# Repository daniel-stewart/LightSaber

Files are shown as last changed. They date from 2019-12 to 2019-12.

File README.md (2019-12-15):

# LightSaber
This repo contains files related to creating 3D lightsabers in Blender that can then be printed out and electroincs inserted. 
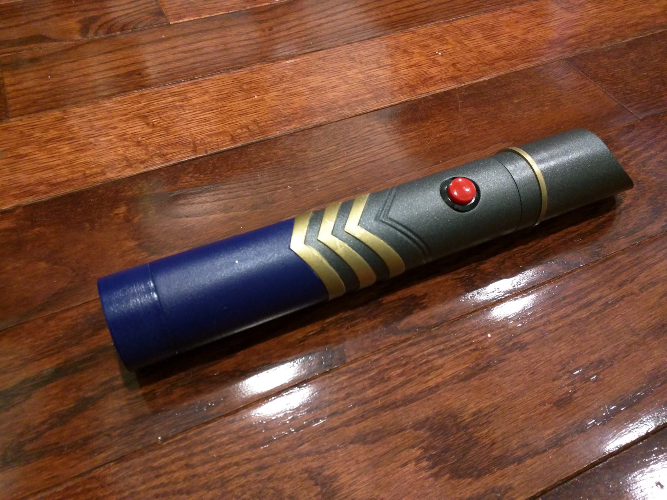
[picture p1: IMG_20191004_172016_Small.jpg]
Lightsaer


## Light Saber Maker Python File
This file will create the basic parts for a lightsaber.
1) Open Blender 2.8 or above.
2) Go to the __Scripting__ tab
3) Choose the open button in the editor and load the LightSaberMaker.py file.
4) Hit __Run Scripts__ button.

The basic parts should be created for you. They are very large compared to Blender units because, by default, Blender exports with 1m = 1mm when exporting STL files. Yes, I could change the default, but I tried to make it easy on my students by allowing them to simply export with default settings.

At the bottom of the Python file you'll see the calls to the various functions which create the hilt, pommel, and blade holder. You can alter the parameters that are used to create the parts. You should be able to look at the function definitions to see what each parameter does. The basic parameters control the number of vertices around, the number of threads, the radius of the lightsaber, and the thread profile.

This just creates parts from which you can continue to make into what you want. They should screw together just fine once printed, assuming you've made the number of threads for male and female such that they fit. 

The Blade Holder was sized to fit standard blades you can get within this hobby space. For example, I bought a blade tube from [The Custom Saber Shop](https://www.thecustomsabershop.com/1-Thick-walled-Trans-White-PolyC-40-long-P528.aspx) and it fits just fine. 

## M4 Lightsaber Code
The M4 Lightsaber Python file is the code that can be loaded onto an [Adafruit M4 Express Feather](https://www.adafruit.com/product/3857) + [PropWing](https://www.adafruit.com/product/3988) to turn the lightsaber on and off. It is very basic code that turns the lightsaber on with one press of the external button and turns it back off when the button is pressed again. The sounds are standard 22kHz, 16-bit WAV files. A very basic usage of the "tap" detection is used to play a sound when lightsabers are hit and momentarily turn the blade all white. I have not included the WAV files, as they are not mine to include. Search the web for whatever sound files you like. 

I used a [standard battery common for lightsabers](https://www.thecustomsabershop.com/JST-Sony-Li-Ion-18650-37V-15A-3120mAh-PCB-Protected-Rechargeable-Battery-P1451.aspx).

I bought regular 22mm speakers off the Internet to use for my sound. 

## Chassis
I've included STL files of the chassis I used to hold the electronics. Not the best design in the world, but it worked.
I designed the hilt such that the chassis slides down and is stopped near the bottom. The inside radius of the tube is simply smaller at th bottom, stopping the chassis from falling all the way through. I held my chassis in place with the button. The button is positioned such that it prevents the chassis from sliding up. Simple, but it works. The distance from the center of the button to the top of the set of points inside the hilt where it begins getting smaller is 142.69 m.

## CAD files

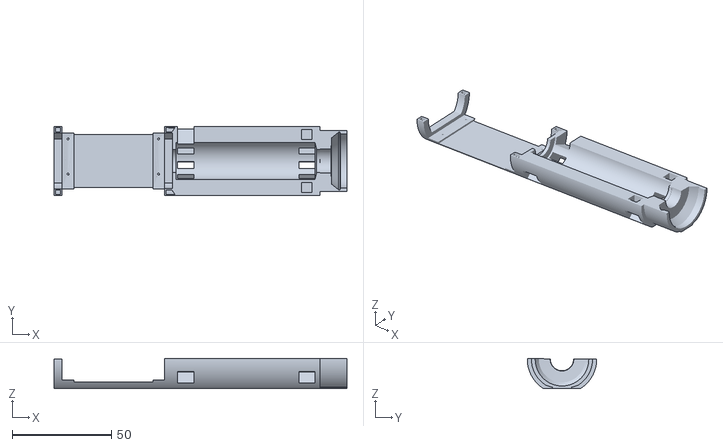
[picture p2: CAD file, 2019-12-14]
BatteryChassis6PrintReady2-Cylinder_004.stl
147.7 x 35.0 x 15.3

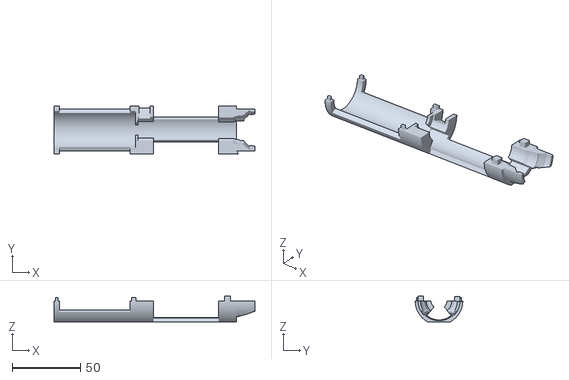
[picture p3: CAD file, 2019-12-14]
BatteryChassis6PrintReady2-Cylinder_003.stl
147.7 x 35.0 x 19.0

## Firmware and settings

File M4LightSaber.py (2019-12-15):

'''
Copyright 2019, Daniel Stewart

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
You should have received a copy of the GNU General Public License
along with this program.  If not, see <https://www.gnu.org/licenses/>.
'''
import board
import time
import neopixel
import digitalio
import busio
import adafruit_lis3dh
import random

try:
    from audiocore import WaveFile
except ImportError:
    from audioio import WaveFile

try:
    from audioio import AudioOut
except ImportError:
    try:
        from audiopwmio import PWMAudioOut as AudioOut
    except ImportError:
        pass  # not always supported by every board!

# define constants
COLOR=(0,0,255)
NUM_PIXELS = 131
NEOPIXEL_PIN = board.D5
POWER_PIN = board.D10
SWITCH_PIN = board.D9

# set up audio
audiofiles = ["sounds/LSOn.wav", "sounds/LSOff.wav", "sounds/LightSaberClash1.wav", "sounds/LightSaberClash2.wav",
              "sounds/LightSaberClash3.wav", "sounds/LightSaberClash4.wav"]
audio = AudioOut(board.A0)

# Set up NeoPixels
neopixels = neopixel.NeoPixel(NEOPIXEL_PIN, NUM_PIXELS, brightness=1)
neopixels.fill((0,0,0))
#neopixels.show()

# Set up on/off button
button = digitalio.DigitalInOut(SWITCH_PIN)
button.switch_to_input(pull=digitalio.Pull.UP)
prevPress = False
on = False
clashNum = 2

# Set up accelerometer on I2C bus, 4G range:
i2c = busio.I2C(board.SCL, board.SDA)
int1 = digitalio.DigitalInOut(board.D6)
lis3dh = adafruit_lis3dh.LIS3DH_I2C(i2c, int1=int1)
lis3dh.range = adafruit_lis3dh.RANGE_8_G
lis3dh.set_tap(1, 90, time_limit=4, time_latency=50, time_window=255)

enable = digitalio.DigitalInOut(POWER_PIN)
enable.direction = digitalio.Direction.OUTPUT
enable.value = False

redled = digitalio.DigitalInOut(board.D13)
redled.direction = digitalio.Direction.OUTPUT
led = neopixel.NeoPixel(board.NEOPIXEL, 1);
led.brightness = 0.2

redled.value = False
def play_file(filename):
    print("Playing file: " + filename)
    wave_file = open(filename, "rb")
    with WaveFile(wave_file) as wave:
        audio.play(wave)
        while audio.playing:
            pass
        wave_file.close()
    print("Finished")

def lightSaberOn():
    i = 0
    enable.value = True
    wave_file = open(audiofiles[0], "rb")
    redled.value = True
    with WaveFile(wave_file) as wave:
        audio.play(wave)
        while audio.playing:
            neopixels[i] = (0,0,255)
            i = (i + 1) % NUM_PIXELS
        wave_file.close()
    print("Finished")

def lightSaberOff():
    wave_file = open(audiofiles[1], "rb")
    redled.value = False
    i = NUM_PIXELS - 1
    with WaveFile(wave_file) as wave:
        audio.play(wave)
        while audio.playing:
            neopixels[i] = (0,0,0)
            i = (i - 1)
            if i < 0:
                i = 0
        wave_file.close()
    enable.value = False
    print("Finished")

def flashOnClash():
    global clashNum
    wave_file = open(audiofiles[clashNum], "rb")
    with WaveFile(wave_file) as wave:
        audio.play(wave)
        neopixels.fill((255,255,255))
        led.fill((255,255,255))
        while audio.playing:
            neopixels.fill((0,0,255))
            led.fill((0,0,255))
        wave_file.close()
    clashNum = random.randint(2,5)

while True:
    x,y,z = lis3dh.acceleration
    if lis3dh.tapped and on:
        flashOnClash()
    if x > 8 and y < 1 and z < 1:
        led[0] = (255,255,0)
    elif x < 1 and y > 8 and z < 1:
        led[0] = (0,255,255)
    elif x < 1 and y < 1 and z > 8:
        led[0] = (255,0,255)
    else:
        led[0] = (0,0,0)
    if not button.value and not prevPress:
        if not on:
            lightSaberOn()
        else:
            lightSaberOff()
        prevPressfor = True
        on = not on
    elif button.value and prevPress:
        prevPress = False

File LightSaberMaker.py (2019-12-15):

'''
Copyright 2019, Daniel Stewart

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
You should have received a copy of the GNU General Public License
along with this program.  If not, see <https://www.gnu.org/licenses/>.
'''
import bpy
import bmesh
from math import *

def createMeshFromData(name, origin, verts, edges, faces):
    # Create mesh and object
    mesh = bpy.data.meshes.new(name+'Mesh')
    ob = bpy.data.objects.new(name, mesh)
    ob.location = origin
    ob.show_name = False
    # Link object to scene and make active
    bpy.context.collection.objects.link(ob)
    ob.select_set(True)
    # Create mesh from given verts, faces.
    mesh.from_pydata(verts, edges, faces)
    bm = bmesh.new()
    bm.from_mesh(mesh)
    bmesh.ops.remove_doubles(bm, verts=bm.verts, dist=0.0001)
    bmesh.ops.recalc_face_normals(bm, faces=bm.faces)
    bm.to_mesh(mesh)
    mesh.update()
    bm.clear()

    bm.free()
    # Update mesh with new data
    mesh.update()

def createCircularPolys(VerticesPerLoop, verts, faces, radius, zoffset, startVert, startFace, joinVert, joinFace):
    angle = 0
    for i in range(VerticesPerLoop):
        angle = i * 2 * pi / VerticesPerLoop
        x = radius * cos(angle)
        y = radius * sin(angle)
        z = zoffset
       
        verts[startVert + i][0] = x
        verts[startVert + i][1] = y
        verts[startVert + i][2] = z
   
    for i in range(VerticesPerLoop - 1):
        faces[startFace + i][0] = startVert + i
        faces[startFace + i][1] = startVert + i + 1
        faces[startFace + i][2] = joinVert + 1 + i
        faces[startFace + i][3] = joinVert + i
   
    faces[startFace + VerticesPerLoop - 1][0] = startVert + VerticesPerLoop - 1
    faces[startFace + VerticesPerLoop - 1][1] = startVert
    faces[startFace + VerticesPerLoop - 1][2] = joinVert
    faces[startFace + VerticesPerLoop - 1][3] = joinVert + VerticesPerLoop - 1
   
def joinCircularPolys(VerticesPerLoop, verts, faces, startVert, startFace, joinVert):
    for i in range(VerticesPerLoop - 1):
        faces[startFace + i][0] = startVert + i
        faces[startFace + i][1] = startVert + i + 1
        faces[startFace + i][2] = joinVert + 1 + i
        faces[startFace + i][3] = joinVert + i
   
    faces[startFace + VerticesPerLoop - 1][0] = startVert + VerticesPerLoop - 1
    faces[startFace + VerticesPerLoop - 1][1] = startVert
    faces[startFace + VerticesPerLoop - 1][2] = joinVert
    faces[startFace + VerticesPerLoop - 1][3] = joinVert + VerticesPerLoop - 1

def createThreads(VerticesPerLoop, verts, faces, startVert, startFace, Loops, R, r, h1, h2, h3, h4, falloffRate, zoffset, femaleThreads = False):
    # Code
    H = h1 + h2 + h3 + h4

    #build array of profile points
    ProfilePoints = []
    ProfilePoints.append( [r, 0, 0] )
    ProfilePoints.append( [R, 0, h1] )
    if h2 > 0:
        ProfilePoints.append( [R, 0, h1 + h2] )
    ProfilePoints.append( [r, 0, h1 + h2 + h3] )
    if h4 > 0:
        ProfilePoints.append( [r, 0, h1 + h2 + h3 + h4] )

    N = len(ProfilePoints)

    # Create the bottom row
    angle = 0
    for i in range(VerticesPerLoop):
        angle = i * 2 * pi / VerticesPerLoop
        radius = r
        x = radius * cos(angle)
        y = radius * sin(angle)
        z = zoffset
       
        verts[startVert + i][0] = x
        verts[startVert + i][1] = y
        verts[startVert + i][2] = z

    faces[startFace][0] = startVert
    faces[startFace][1] = startVert + VerticesPerLoop
    faces[startFace][2] = startVert + VerticesPerLoop + N
    faces[startFace][3] = startVert + 1

    for i in range(1,VerticesPerLoop-1):
        faces[startFace + i][0] = startVert + i
        faces[startFace + i][1] = startVert + i * N + VerticesPerLoop
        faces[startFace + i][2] = startVert + i * N + VerticesPerLoop + N
        faces[startFace + i][3] = startVert + i + 1

    # Just to ensure we have the right size
    faces[startFace + VerticesPerLoop - 1] = [0 for _ in range(N+2)]
   
    # This one face has N + 2 vertices, not just 4.
    faces[startFace + VerticesPerLoop - 1][0] = startVert + VerticesPerLoop - 1
    faces[startFace + VerticesPerLoop - 1][1] = startVert + (VerticesPerLoop - 2) * N + VerticesPerLoop + N
    for i in range(1,N):
        faces[startFace + VerticesPerLoop - 1][i+1] =  startVert + VerticesPerLoop + (N - i)
    faces[startFace + VerticesPerLoop - 1][N+1] = startVert + VerticesPerLoop

    # Here we actually create the threads.
    # go around a circle. for each point in ProfilePoints array, create a vertex
    angle = 0
    zMax = ProfilePoints[N-1][2] + (Loops - 1) * H + zoffset
    for i in range(VerticesPerLoop * Loops + 1):
        for j in range(N):
            angle = i * 2 * pi / VerticesPerLoop
            # falloff applies to outer rings only
            u = i / (VerticesPerLoop * Loops)
            radius = r + (R - r) * (1 - 6*(pow(2 * u - 1, falloffRate * 4)/2 - pow(2 * u - 1, falloffRate * 6)/3)) if ProfilePoints[j][0] == R else r

            x = radius * cos(angle)
            y = radius * sin(angle)
            z = ProfilePoints[j][2] + i / VerticesPerLoop * H + zoffset
            # Check for maxing out if necessary
            if femaleThreads and (z > zMax):
                z = zMax

            verts[startVert + N*i + j + VerticesPerLoop][0] = x
            verts[startVert + N*i + j + VerticesPerLoop][1] = y
            verts[startVert + N*i + j + VerticesPerLoop][2] = z
    # now build face array
    for i in range(VerticesPerLoop * Loops):
        for j in range(N - 1):
            faces[startFace + (N - 1) * i + j + VerticesPerLoop][0] = startVert + N * i + j + VerticesPerLoop
            faces[startFace + (N - 1) * i + j + VerticesPerLoop][1] = startVert + N * i + 1 + j + VerticesPerLoop
            faces[startFace + (N - 1) * i + j + VerticesPerLoop][2] = startVert + N * (i + 1) + 1 + j + VerticesPerLoop
            faces[startFace + (N - 1) * i + j + VerticesPerLoop][3] = startVert + N * (i + 1) + j + VerticesPerLoop

    # Now create the top edge
    angle = 0
    for i in range(VerticesPerLoop):
        angle = i * 2 * pi / VerticesPerLoop
        radius = r
        x = radius * cos(angle)
        y = radius * sin(angle)
        if femaleThreads:
            z = Loops * H + zoffset
        else:
            z = (Loops + 1)*H + zoffset
       
        verts[startVert + N * (VerticesPerLoop * Loops + 1) + i + VerticesPerLoop][0] = x
        verts[startVert + N * (VerticesPerLoop * Loops + 1) + i + VerticesPerLoop][1] = y
        verts[startVert + N * (VerticesPerLoop * Loops + 1) + i + VerticesPerLoop][2] = z
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

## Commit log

2019-12-14 Image of printed and painted lightsaber
2019-12-14 Chassis for the Lightsaber electronics
    [BatteryChassis6PrintReady2-Cylinder_003.stl, BatteryChassis6PrintReady2-Cylinder_004.stl]

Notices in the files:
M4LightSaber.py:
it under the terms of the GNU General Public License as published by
